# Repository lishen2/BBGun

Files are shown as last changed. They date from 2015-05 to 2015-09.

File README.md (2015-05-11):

BBGun
=============
BBGUN is an infrared shooting system used for entertainment purposes. The project Milestag gave us a lot of inspiration.
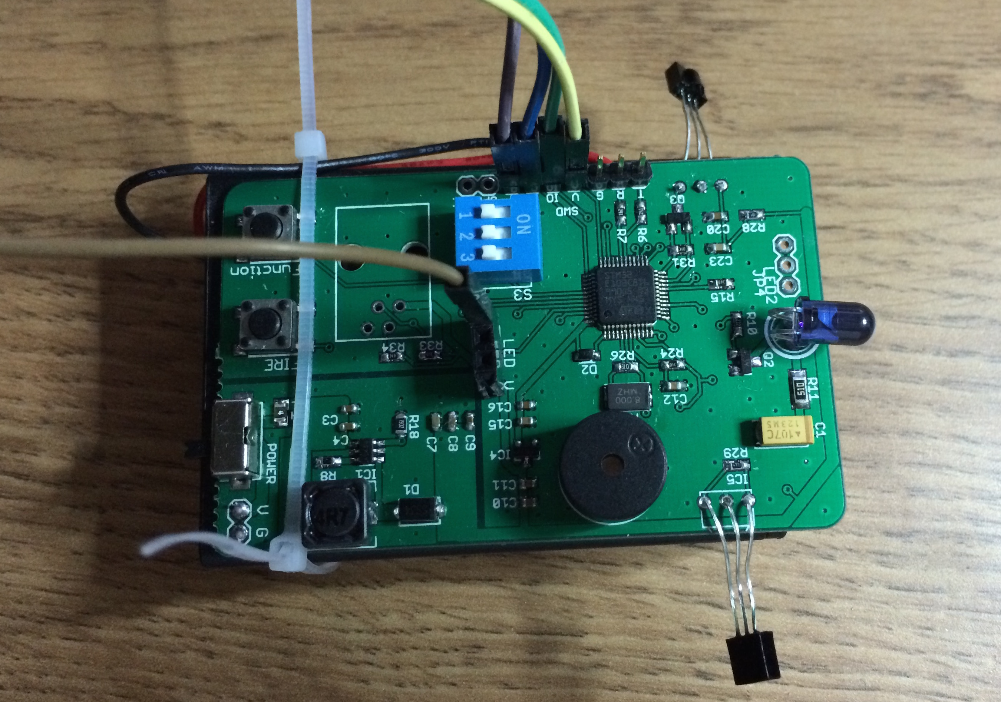
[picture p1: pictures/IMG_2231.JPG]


Hareware resources
-------
* one TSAL6100 IR emitter, two HS0038B IR reciver.
* one RJ9 socket used to connect external reciver(not implemented yet).
* one three key dil switch, used to set group.
* one buzzer controlled by PWM pin.
* two push buttons.

Progress
--------
20150427: First PCB design.     
20150503: Make first test board.  
20150505: LED driver code and buzzer driver code finish.  
20150510: Finish all drivers except IR system.

Developing blog
--------
http://lsgeek.blogspot.com

BBGun
=============
BBGun是一个用于娱乐目的的红外射击系统(真人CS)。Milestag项目给了我们很多启发。

硬件资源
-------
* 一个TSAL6100发射管，两个HS0038B接收管
* 一个RJ9接口用于连接外置接收器（暂未实现）
* 一个三键拨码开关，用于设置分组
* 一个PWM引脚控制的蜂鸣器
* 两个按键

当前进度
--------
20150427: 完成PCB设计   
20150503: 完成第一块PCB的制作   
20150505: 完成LED驱动、蜂鸣器驱动  
20150510: 完成除IR系统外的所有驱动

开发博客
--------
http://blog.sina.com.cn/lgeek

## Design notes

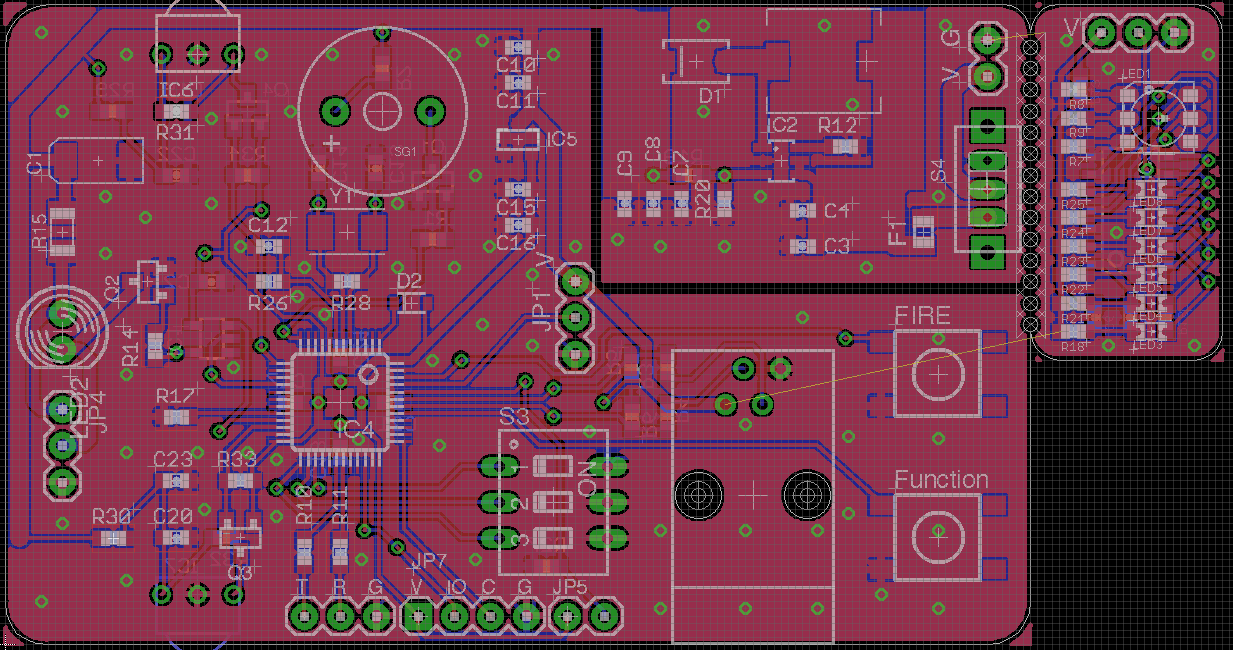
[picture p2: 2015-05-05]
pictures/pcb.png

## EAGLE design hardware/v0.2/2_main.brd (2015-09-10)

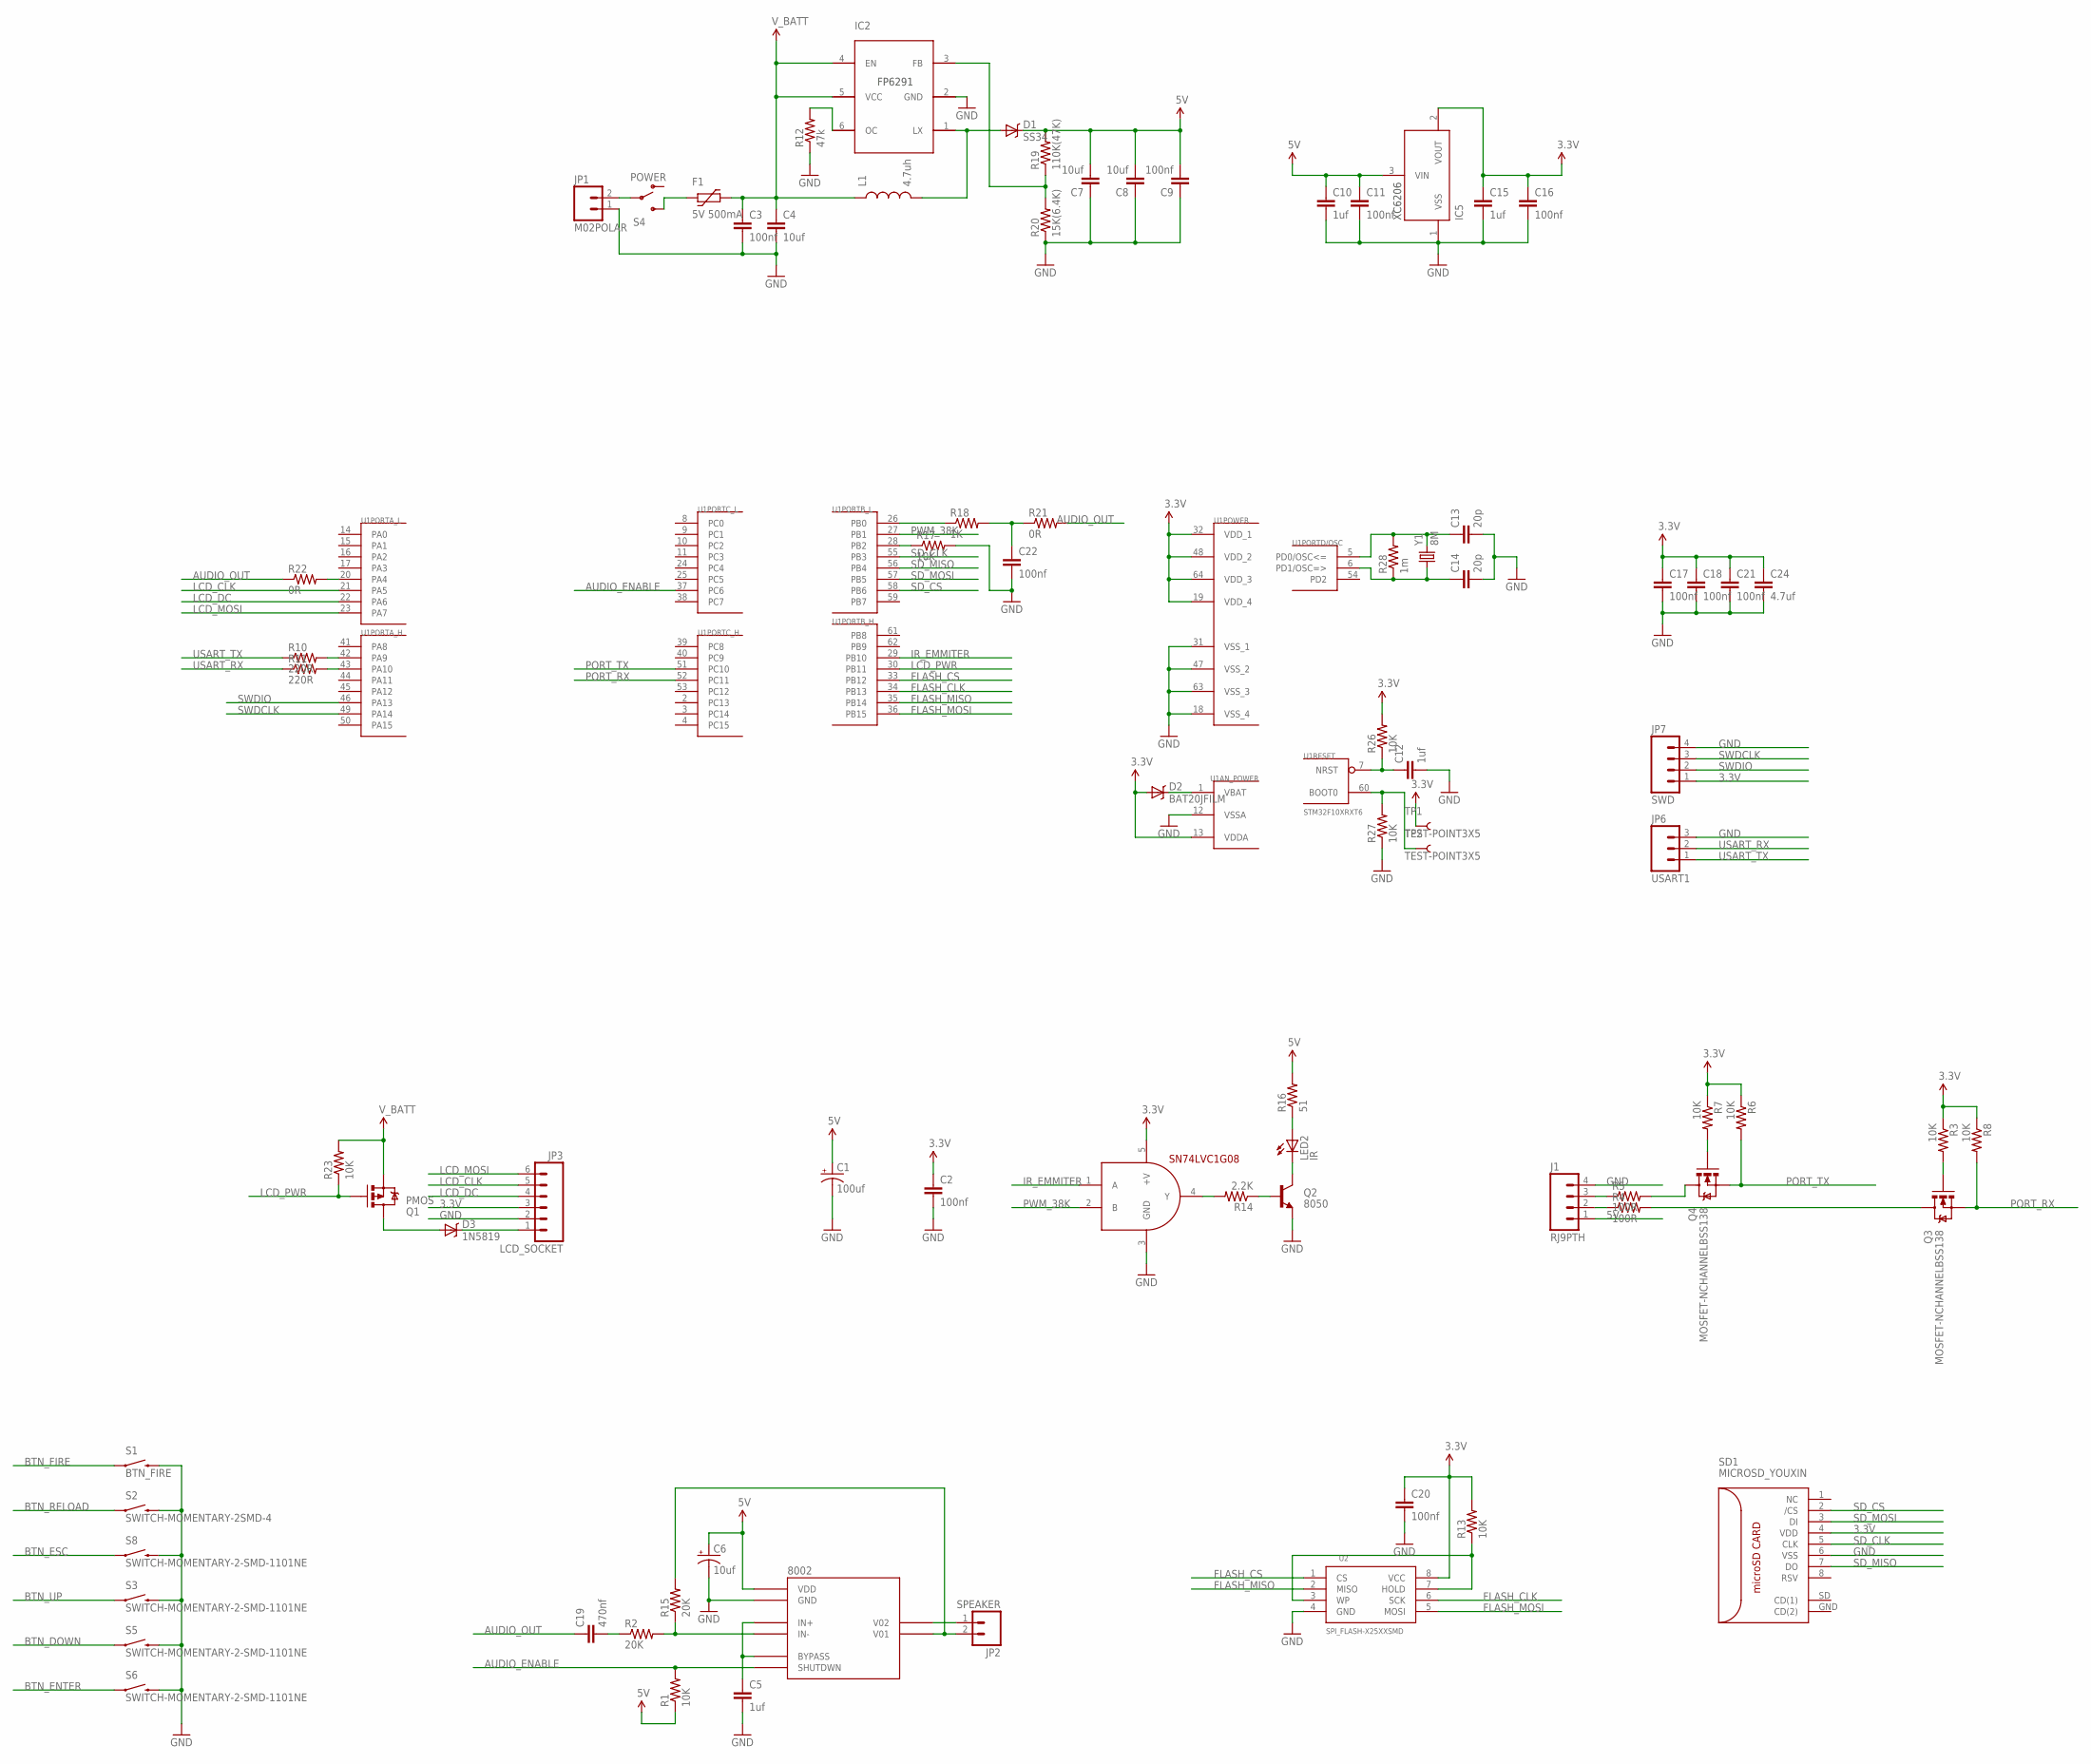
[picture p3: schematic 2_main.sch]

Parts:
8002: LM4871; SO08
C1: 100uf; EIA6032
C2, C3, C9, C11, C16, C17, C18, C20, C21, C22: 100nf; 0603-CAP
C4, C7, C8: 10uf; 0603-CAP
C5, C10, C12, C15: 1uf; 0603-CAP
C6: 10uf; EIA3216-KIT
C13, C14: 20p; 0603-CAP
C19: 470nf; 0603-CAP
C24: 4.7uf; 0603-CAP
D1: SS34; SMA-DIODE
D2: BAT20JFILM; SOD-323
D3: 1N5819; SOD-323
F1: 5V 500mA; R0805
IC1: SN74LVC1G08; SOT23-5
IC2: FP6291; SOT23-6
IC5: XC6206; SOT23-3
J1: RJ9PTH; RJ9
JP1: M02POLAR; MOLEX-1X2
JP2: SPEAKER; MOLEX-1X2
JP3: LCD_SOCKET; MOLEX-1X6
JP6: USART1; 1X03
JP7: SWD; 1X04
L1: 4.7uh; CR75_V2
LED2: IR; LED5MM
Q1: PMOS; SOT23-3
Q2: 8050; SOT23
Q3, Q4: MOSFET-NCHANNELBSS138; SOT23
R1, R3, R6, R7, R8, R13, R17, R23, R26, R27: 10K; 0603-RES
R2, R15: 20K; 0603-RES
R4, R5: 100R; 0603-RES
R10, R11: 220R; 0603-RES
R12: 47k; 0603-RES
R14: 2.2K; 0603-RES
R16: 51; 0603-RES
R18: 1K; 0603-RES
R19: 110K(47K); 0603-RES
R20: 15K(6.4K); 0603-RES
R21, R22: 0R; 0603-RES
R28: 1m; 0603-RES
S1: BTN_FIRE; TACTILE_SWITCH_TALL
S2: SWITCH-MOMENTARY-2SMD-4; TACTILE_SWITCH_TALL
S3, S5, S6, S8: SWITCH-MOMENTARY-2-SMD-1101NE; TACTILE-SWITCH-1101NE
S4: POWER; SWITCH-SPDT-AM#6
SD1: MICROSD_YOUXIN; MICRO_SD_YOUXIN
TP1, TP2: TEST-POINT3X5; PAD.03X.05
U1: STM32F10XRXT6; TQFP64
U2: SPI_FLASH-X25XXSMD; SO08
Y1: 8M; CRYSTAL-TXC-7A

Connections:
3.3V: C2.1, C15.1, C16.1, C17.1, C18.1, C20.1, C21.1, C24.1, D2.2 (A), IC1.5 (+V), IC5.2 (VOUT), JP3.3, JP7.1, R3.1, R6.1, R7.1, R8.1, R13.2, R26.2, SD1.4 (VDD), TP1.P$1, U1.13 (VDDA), U1.19 (VDD_4), U1.32 (VDD_1), U1.48 (VDD_2), U1.64 (VDD_3), U2.8 (VCC)
5V: 8002.6 (VDD), C1.P$1 (+), C6.A (+), C7.2, C8.2, C9.2, C10.1, C11.1, D1.C, IC5.3 (VIN), J1.1, R1.1, R16.2, R19.2
AUDIO_ENABLE: 8002.1 (SHUTDWN), R1.2, U1.37 (PC6)
AUDIO_OUT: C19.1, R21.2, R22.1
BTN_DOWN: S5.P$1 (1)
BTN_ENTER: S6.P$1 (1)
BTN_ESC: S8.P$1 (1)
BTN_FIRE: S1.A2 (1)
BTN_RELOAD: S2.A2 (1)
BTN_UP: S3.P$1 (1)
FLASH_CLK: U1.34 (PB13), U2.6 (SCK)
FLASH_CS: U1.33 (PB12), U2.1 (CS)
FLASH_MISO: U1.35 (PB14), U2.2 (MISO)
FLASH_MOSI: U1.36 (PB15), U2.5 (MOSI)
GND: 8002.7 (GND), C1.P$2 (-), C2.2, C3.2, C4.2, C5.2, C6.C (-), C7.1, C8.1, C9.1, C10.2, C11.2, C12.2, C13.2, C14.2, C15.2, C16.2, C17.2, C18.2, C20.2, C21.2, C22.2, C24.2, IC1.3 (GND), IC2.2 (GND), IC5.1 (VSS), J1.4, JP1.1, JP3.2, JP6.3, JP7.4, Q2.2 (E), R12.1, R17.2, R20.1, R27.1, S1.B2 (2), S2.B2 (2), S3.P$2 (2), S5.P$2 (2), S6.P$2 (2), S8.P$2 (2), SD1.6 (VSS), U1.12 (VSSA), U1.18 (VSS_4), U1.31 (VSS_1), U1.47 (VSS_2), U1.63 (VSS_3), U2.4 (GND)
IR_EMMITER: IC1.1 (A), U1.29 (PB10)
LCD_CLK: JP3.5, U1.21 (PA5)
LCD_DC: JP3.4, U1.22 (PA6)
LCD_MOSI: JP3.6, U1.23 (PA7)
LCD_PWR: Q1.1 (G), R23.1, U1.30 (PB11)
unnamed: R17.1, U1.28 (PB2)
unnamed: R27.2, TP2.P$1, U1.60 (BOOT0)
unnamed: C13.1, R28.2, U1.5 (PD0/OSC<=), Y1.P$2 (2)
unnamed: C14.1, R28.1, U1.6 (PD1/OSC=>), Y1.P$1 (1)
unnamed: D2.1 (C), U1.1 (VBAT)
unnamed: IC1.4 (Y), R14.2
unnamed: JP1.2, S4.2
unnamed: LED2.K (C), Q2.3 (C)
unnamed: Q2.1 (B), R14.1
unnamed: F1.1, S4.3 (S)
unnamed: Q3.3 (D), R4.2
unnamed: J1.3, R5.1
unnamed: Q4.3 (D), R5.2
unnamed: R18.1, U1.26 (PB0)
unnamed: 8002.8 (V02), JP2.1
unnamed: Q4.1 (G), R7.2
unnamed: Q3.1 (G), R3.2
unnamed: 8002.5 (V01), JP2.2, R15.2
unnamed: C19.2, R2.1
unnamed: LED2.A, R16.1
unnamed: 8002.4 (IN-), R2.2, R15.1
unnamed: D1.A, IC2.1 (LX), L1.P$2 (2)
unnamed: IC2.6 (OC), R12.2
unnamed: 8002.2 (BYPASS), 8002.3 (IN+), C5.1
unnamed: IC2.3 (FB), R19.1, R20.2
unnamed: R13.1, U2.3 (WP), U2.7 (HOLD)
unnamed: R10.2, U1.42 (PA9)
unnamed: R11.2, U1.43 (PA10)
unnamed: D3.1 (C), JP3.1
unnamed: C22.1, R18.2, R21.1
unnamed: R22.2, U1.20 (PA4)
unnamed: D3.2 (A), Q1.3 (D)
unnamed: J1.2, R4.1
unnamed: C12.1, R26.1, U1.7 (NRST)
PORT_RX: Q3.2 (S), R8.2, U1.52 (PC11)
PORT_TX: Q4.2 (S), R6.2, U1.51 (PC10)
PWM_38K: IC1.2 (B), U1.27 (PB1)
SD_CLK: SD1.5 (CLK), U1.55 (PB3)
SD_CS: SD1.2 (/CS), U1.58 (PB6)
SD_MISO: SD1.7 (DO), U1.56 (PB4)
SD_MOSI: SD1.3 (DI), U1.57 (PB5)
SWDCLK: JP7.3, U1.49 (PA14)
SWDIO: JP7.2, U1.46 (PA13)
USART_RX: JP6.2, R11.1
USART_TX: JP6.1, R10.1
V_BATT: C3.1, C4.1, F1.2, IC2.4 (EN), IC2.5 (VCC), L1.P$1 (1), Q1.2 (S), R23.2

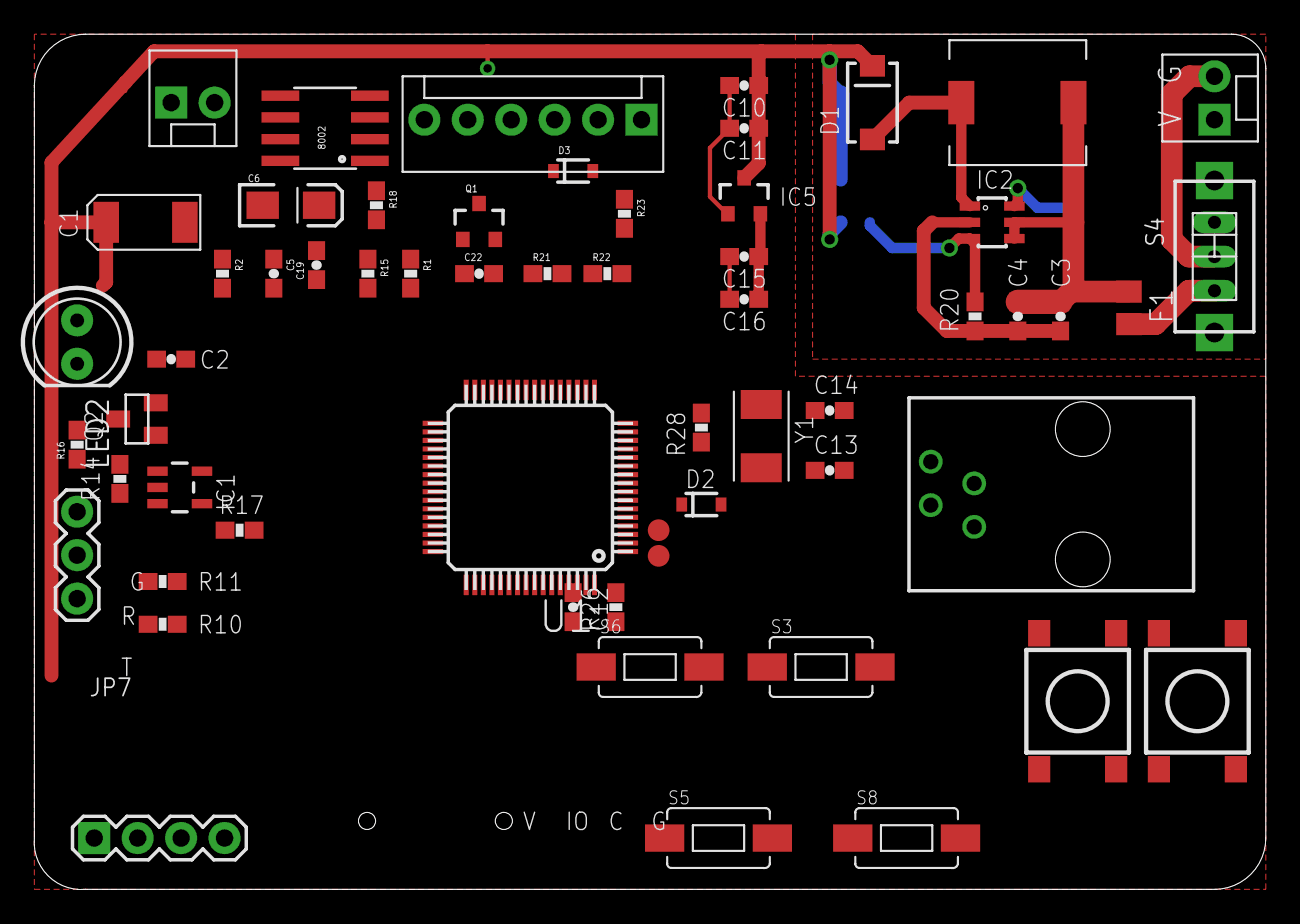
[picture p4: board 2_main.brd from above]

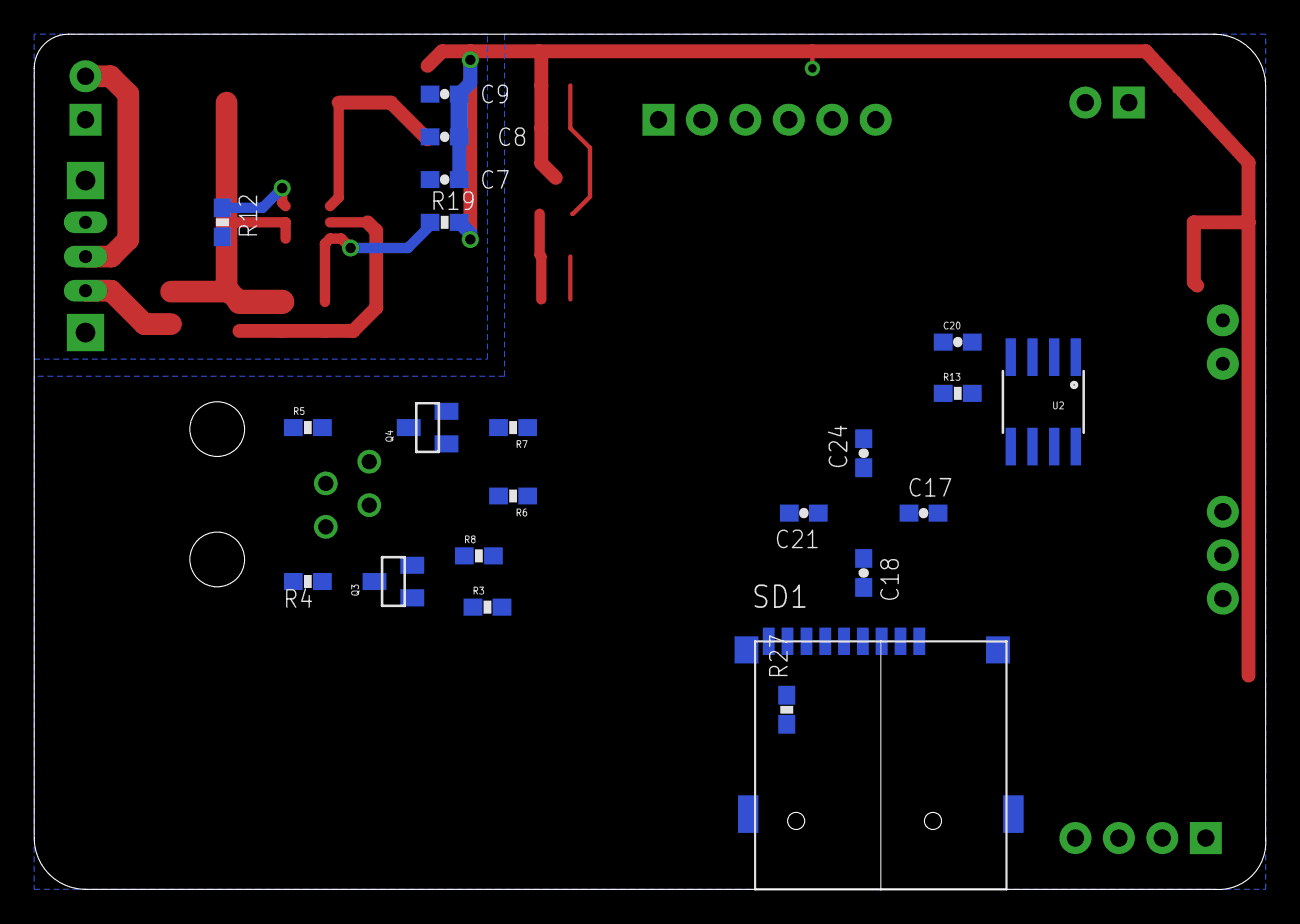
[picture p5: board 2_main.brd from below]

Board: 2 copper layers, 72.0 x 50.0 mm, 81 parts (22 on the bottom side), 60 nets.

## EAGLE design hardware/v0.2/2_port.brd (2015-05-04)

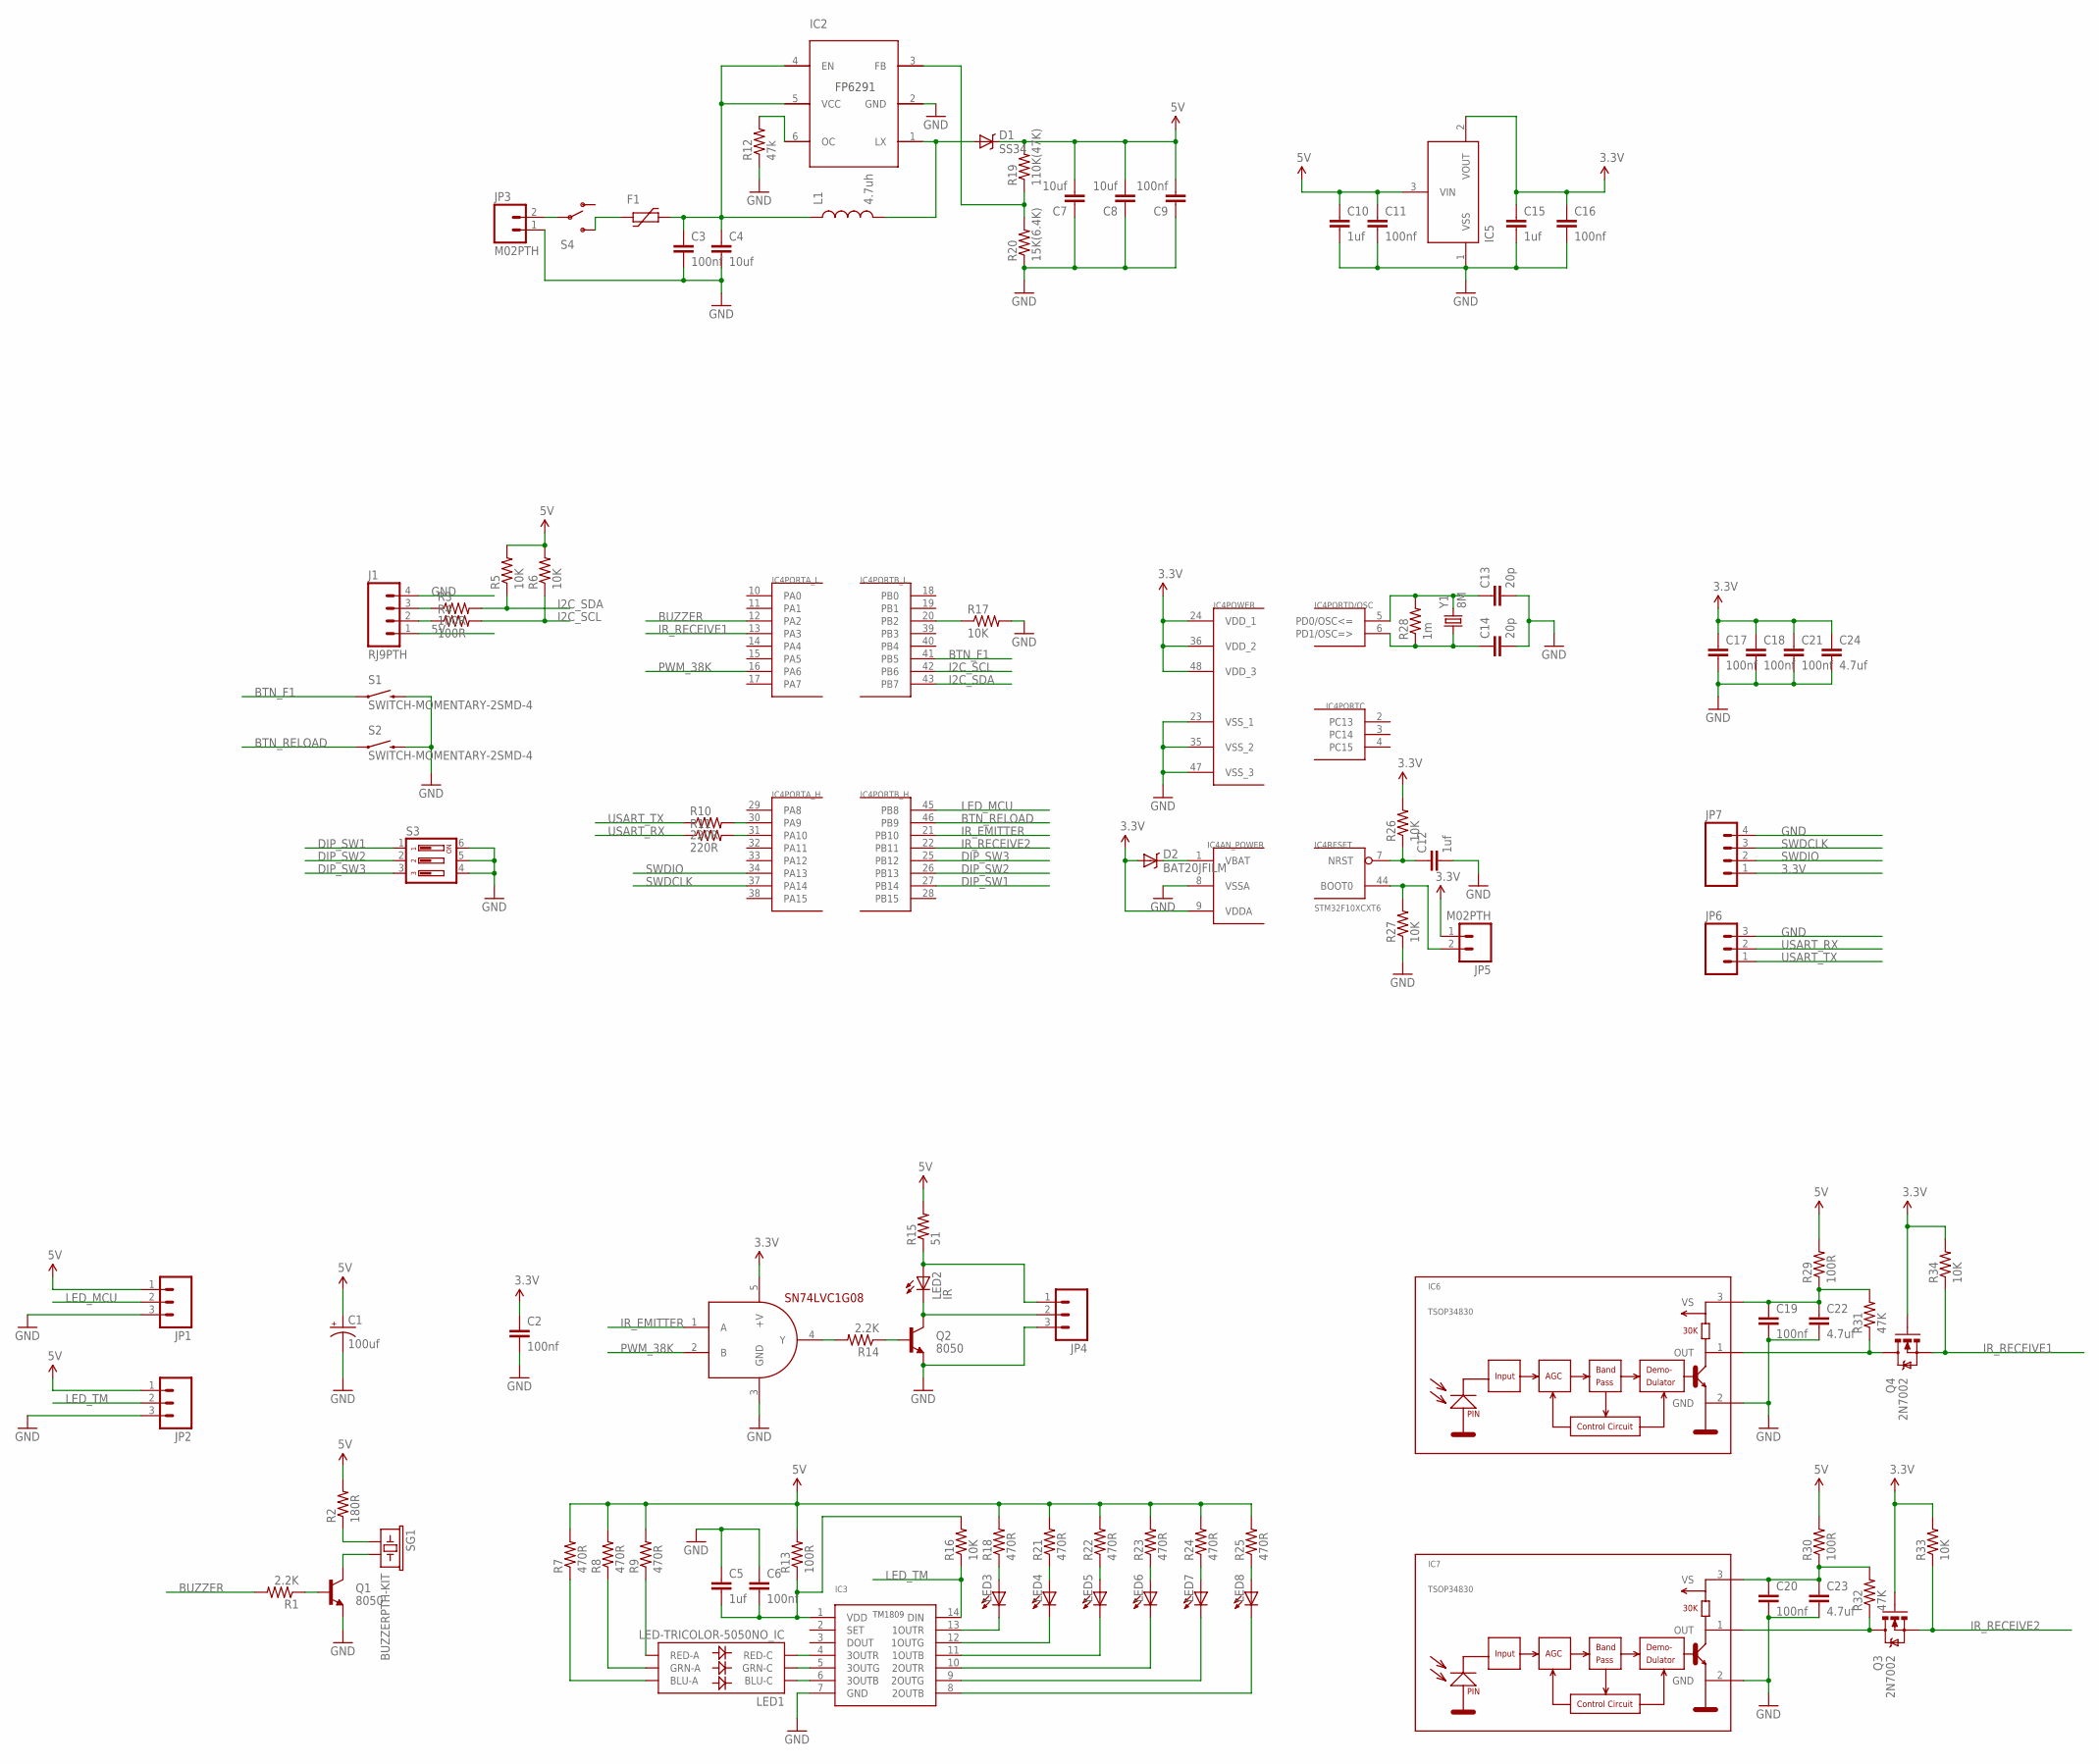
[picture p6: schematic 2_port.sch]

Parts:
C1: 100uf; EIA6032
C2, C3, C6, C9, C11, C16, C17, C18, C19, C20, C21: 100nf; 0603-CAP
C4, C7, C8: 10uf; 0603-CAP
C5, C10, C12, C15: 1uf; 0603-CAP
C13, C14: 20p; 0603-CAP
C22, C23, C24: 4.7uf; 0603-CAP
D1: SS34; SMA-DIODE
D2: BAT20JFILM; SOD-323
F1: PTC-FUSE; R0805
IC1: SN74LVC1G08; SOT23-5
IC2: FP6291; SOT23-6
IC3: TM1809; SOP-14
IC4: STM32F10XCXT6; TQFP48
IC5: XC6206; SOT23-3
IC6, IC7: TSOP34830; TSOP348
J1: RJ9PTH; RJ9
JP1, JP2, JP4, JP6: M03PTH; 1X03
JP3, JP5: M02PTH; 1X02
JP7: M04PTH; 1X04
L1: 4.7uh; CR75_V2
LED1: LED-TRICOLOR-5050NO_IC; LED-TRICOLOR-5050
LED2: IR; LED5MM
LED3, LED4, LED5, LED6, LED7, LED8: LED0805; CHIPLED_0805
Q1, Q2: 8050; SOT23
Q3, Q4: 2N7002; SOT23
R1, R14: 2.2K; 0603-RES
R2: 180R; 0603-RES
R3, R4, R13, R29, R30: 100R; 0603-RES
R5, R6, R16, R17, R26, R27, R33, R34: 10K; 0603-RES
R7, R8, R9, R18, R21, R22, R23, R24, R25: 470R; 0603-RES
R10, R11: 220R; 0603-RES
R12: 47k; 0603-RES
R15: 51; 1206
R19: 110K(47K); 0603-RES
R20: 15K(6.4K); 0603-RES
R28: 1m; 0603-RES
R31, R32: 47K; 0603-RES
S1, S2: SWITCH-MOMENTARY-2SMD-4; TACTILE_SWITCH_TALL
S3: DIP03YL
S4: SWITCH-SPST3AM6; SWITCH-SPDT-AM#6
SG1: BUZZERPTH-KIT; BUZZER-12MM-KIT
Y1: 8M; CRYSTAL-TXC-7A

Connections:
3.3V: C2.1, C15.1, C16.1, C17.1, C18.1, C21.1, C24.1, D2.2 (A), IC1.5 (+V), IC4.9 (VDDA), IC4.24 (VDD_1), IC4.36 (VDD_2), IC4.48 (VDD_3), IC5.2 (VOUT), JP5.1, JP7.1, Q3.1 (G), Q4.1 (G), R26.2, R33.2, R34.2
5V: C1.P$1 (+), C7.2, C8.2, C9.2, C10.1, C11.1, D1.C, IC5.3 (VIN), J1.1, JP1.1, JP2.1, R2.2, R5.2, R6.2, R7.2, R8.2, R9.2, R13.2, R15.2, R18.2, R19.2, R21.2, R22.2, R23.2, R24.2, R25.2, R29.2, R30.2
BTN_F1: IC4.41 (PB5), S1.A2 (1)
BTN_RELOAD: IC4.46 (PB9), S2.A2 (1)
BUZZER: IC4.12 (PA2), R1.2
DIP_SW1: IC4.27 (PB14), S3.1
DIP_SW2: IC4.26 (PB13), S3.2
DIP_SW3: IC4.25 (PB12), S3.3
GND: C1.P$2 (-), C2.2, C3.2, C4.2, C5.1, C6.1, C7.1, C8.1, C9.1, C10.2, C11.2, C12.2, C13.2, C14.2, C15.2, C16.2, C17.2, C18.2, C19.2, C20.2, C21.2, C22.2, C23.2, C24.2, IC1.3 (GND), IC2.2 (GND), IC3.7 (GND), IC4.8 (VSSA), IC4.23 (VSS_1), IC4.35 (VSS_2), IC4.47 (VSS_3), IC5.1 (VSS), IC6.2 (GND), IC7.2 (GND), J1.4, JP1.3, JP2.3, JP3.1, JP4.3, JP6.3, JP7.4, Q1.2 (E), Q2.2 (E), R12.1, R17.2, R20.1, R27.1, S1.B2 (2), S2.B2 (2), S3.4, S3.5, S3.6
I2C_SCL: IC4.42 (PB6), R4.2, R6.1
I2C_SDA: IC4.43 (PB7), R3.2, R5.1
IR_EMITTER: IC1.1 (A), IC4.21 (PB10)
IR_RECEIVE1: IC4.13 (PA3), Q4.2 (S), R34.1
IR_RECEIVE2: IC4.22 (PB11), Q3.2 (S), R33.1
LED_MCU: IC4.45 (PB8), JP1.2
LED_TM: IC3.14 (DIN), JP2.2, R16.1
unnamed: IC4.20 (PB2), R17.1
unnamed: IC4.44 (BOOT0), JP5.2, R27.2
unnamed: C13.1, IC4.5 (PD0/OSC<=), R28.2, Y1.P$2 (2)
unnamed: C14.1, IC4.6 (PD1/OSC=>), R28.1, Y1.P$1 (1)
unnamed: D2.1 (C), IC4.1 (VBAT)
unnamed: IC1.4 (Y), R14.2
unnamed: JP3.2, S4.2
unnamed: JP4.2, LED2.K (C), Q2.3 (C)
unnamed: Q2.1 (B), R14.1
unnamed: F1.1, S4.3 (S)
unnamed: C19.1, C22.1, IC6.3 (VS), R29.1, R31.2
unnamed: C20.1, C23.1, IC7.3 (VS), R30.1, R32.2
unnamed: IC3.4 (3OUTR), LED1.5 (RED-C)
unnamed: JP4.1, LED2.A, R15.1
unnamed: IC3.5 (3OUTG), LED1.6 (GRN-C)
unnamed: IC3.6 (3OUTB), LED1.4 (BLU-C)
unnamed: LED1.2 (RED-A), R9.1
unnamed: LED1.1 (GRN-A), R8.1
unnamed: LED1.3 (BLU-A), R7.1
unnamed: C3.1, C4.1, F1.2, IC2.4 (EN), IC2.5 (VCC), L1.P$1 (1)
unnamed: IC3.13 (1OUTR), LED3.C
unnamed: D1.A, IC2.1 (LX), L1.P$2 (2)
unnamed: IC2.6 (OC), R12.2
unnamed: LED3.A, R18.1
unnamed: IC2.3 (FB), R19.1, R20.2
unnamed: LED4.A, R21.1
unnamed: IC3.12 (1OUTG), LED4.C
unnamed: IC3.11 (1OUTB), LED5.C
unnamed: IC3.10 (2OUTR), LED6.C
unnamed: IC3.9 (2OUTG), LED7.C
unnamed: IC3.8 (2OUTB), LED8.C
unnamed: LED5.A, R22.1
unnamed: LED6.A, R23.1
unnamed: LED7.A, R24.1
unnamed: LED8.A, R25.1
unnamed: C5.2, C6.2, IC3.1 (VDD), R13.1, R16.2
unnamed: IC4.30 (PA9), R10.2
unnamed: IC4.31 (PA10), R11.2
unnamed: J1.3, R3.1
unnamed: J1.2, R4.1
unnamed: R2.1, SG1.+ (1)
unnamed: Q1.3 (C), SG1.- (2)
unnamed: Q1.1 (B), R1.1
unnamed: C12.1, IC4.7 (NRST), R26.1
unnamed: IC6.1 (OUT), Q4.3 (D), R31.1
unnamed: IC7.1 (OUT), Q3.3 (D), R32.1
PWM_38K: IC1.2 (B), IC4.16 (PA6)
SWDCLK: IC4.37 (PA14), JP7.3
SWDIO: IC4.34 (PA13), JP7.2
USART_RX: JP6.2, R11.1
USART_TX: JP6.1, R10.1

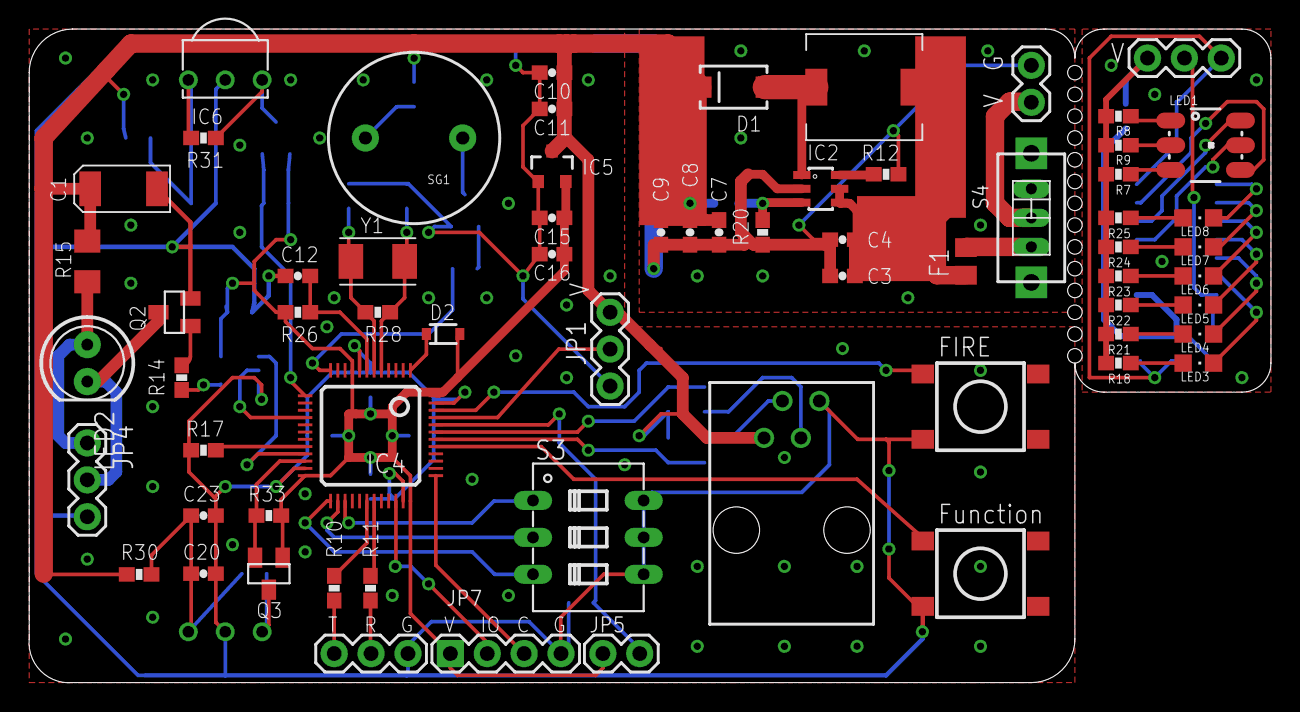
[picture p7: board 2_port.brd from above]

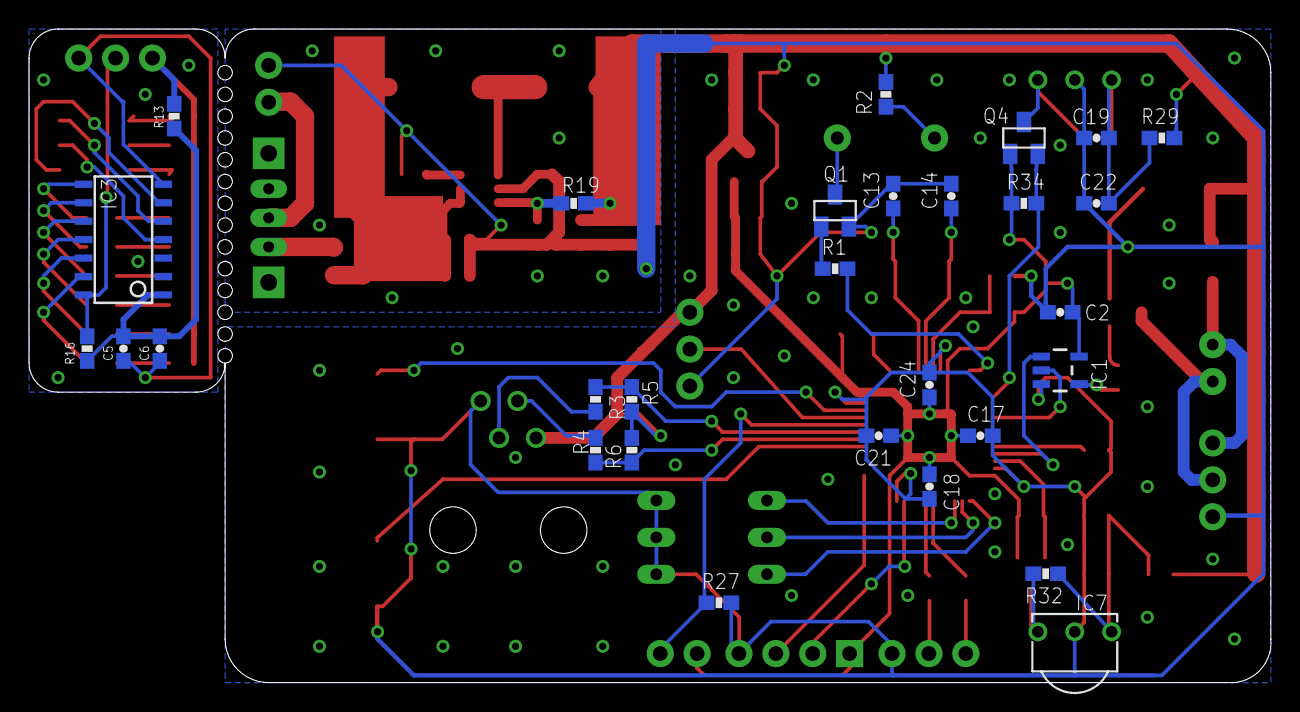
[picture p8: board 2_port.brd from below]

Board: 2 copper layers, 85.5 x 45.0 mm, 95 parts (29 on the bottom side), 67 nets.

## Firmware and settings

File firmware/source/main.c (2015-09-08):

#include <stdio.h>
#include "stm32f10x.h"
#include "public.h"
#include "led.h"
#include "ir.h"
#include "menu.h"
#include "ringbuf.h"
#include "usart_io.h"
#include "button.h"

int main()
{
	system_init();
	usartio_init_usart1(); 
	usartio_init_usart2();
	usartio_init_usart3();
	button_init();
	ir_init();
    
	printf("started\n");

	//ir_send_shot(0x01, 0x02, 0x03);
	while(1){
		
        ir_handle_msg();
        logic_handle_key();

		delay_ms(20);
	}

	return 0;
}

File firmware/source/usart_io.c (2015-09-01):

#include <stdio.h>
#include <string.h>
#include "stm32f10x.h"
#include "ringbuf.h"
#include "usart_io.h"
#include "public.h"

#define USARTIO_FLAG_RXNE  0x20
#define USARTIO_FLAG_TXE   0x80

#define USARTIO_IsFlagSet(USART_ADDR, FLAG) (0 != (USART_ADDR->SR & FLAG))

//USART1 used to print debug information and firmware upgrade
#define USARTIO_USART1_GPIO       GPIOA
#define USARTIO_USART1_GPIO_CLK   RCC_APB2Periph_GPIOA
#define USARTIO_USART1_RxPin      GPIO_Pin_10
#define USARTIO_USART1_TxPin      GPIO_Pin_9
#define USARTIO_USART1_CLK        RCC_APB2Periph_USART1
#define USARTIO_USART1_IRQ        USART1_IRQn

//USART2 and USART3 RX pin connect to two IR receive ICs,
//USART3 TX pin connect IR emitter diode
#define USARTIO_USART2_GPIO      GPIOA
#define USARTIO_USART2_GPIO_CLK  RCC_APB2Periph_GPIOA
#define USARTIO_USART2_RxPin     GPIO_Pin_3
#define USARTIO_USART2_CLK       RCC_APB1Periph_USART2
#define USARTIO_USART2_IRQ       USART2_IRQn

#define USARTIO_USART3_GPIO      GPIOB
#define USARTIO_USART3_GPIO_CLK  RCC_APB2Periph_GPIOB
#define USARTIO_USART3_RxPin     GPIO_Pin_11
#define USARTIO_USART3_TxPin     GPIO_Pin_10
#define USARTIO_USART3_CLK       RCC_APB1Periph_USART3
#define USARTIO_USART3_IRQ       USART3_IRQn

/* USART1 send and receive buffer size */
#define USARTIO_U1_READBUF_SIZE  64 
#define USARTIO_U1_WRITEBUF_SIZE 1024

/* USART2 is receive only, USART3 use polling mode to send, so they both not use send buffer */
#define USARTIO_U2_READBUF_SIZE  256 
#define USARTIO_U3_READBUF_SIZE  256 

static unsigned char g_usart1_readbuf[USARTIO_U1_READBUF_SIZE]; 
static unsigned char g_usart1_writebuf[USARTIO_U1_WRITEBUF_SIZE]; 
struct ringbuf_struct g_Usart1ReadBufHead = {
    0,
    0,
    sizeof(g_usart1_readbuf),
    g_usart1_readbuf,
};
struct ringbuf_struct g_Usart1WriteBufHead = {
    0,
    0,
    sizeof(g_usart1_writebuf),
    g_usart1_writebuf,
};

static unsigned char g_usart2_readbuf[USARTIO_U2_READBUF_SIZE]; 
struct ringbuf_struct g_Usart2ReadBufHead = {
    0,
    0,
    sizeof(g_usart2_readbuf),
    g_usart2_readbuf,
};

static unsigned char g_usart3_readbuf[USARTIO_U3_READBUF_SIZE];  
struct ringbuf_struct g_Usart3ReadBufHead = {
    0,
    0,
    sizeof(g_usart3_readbuf),
    g_usart3_readbuf,
};

static USART_InitTypeDef USART_InitStructure;

int usartio_sendchar(void* port, unsigned char ch)
{  
    int ret;

	//usart1 use interrupt mode
    if (USART1 == port){
	    ret = ringbuf_putchar(&g_Usart1WriteBufHead, ch);
	    USART_ITConfig(port, USART_IT_TXE, ENABLE);
    } 
	else {
        return ERR_FAILED;
    }

    return ret;
}

int usartio_sendchar_polling(void* port, unsigned char ch)
{  
	//usart3 use polling mode
	if (USART3 == port){
	    USART_SendData(port, ch);
	    while(USART_GetFlagStatus(port, USART_FLAG_TXE) == RESET);
    } else {
        return ERR_FAILED;
    }

    return ERR_OK;
}

int usartio_recvchar(void *port, unsigned char *ch, int timeout)
{
    int ret;
    struct ringbuf_struct *readBuf;

    if (USART1 == port){
        readBuf = &g_Usart1ReadBufHead;
    } else if (USART2 == port){
        readBuf = &g_Usart2ReadBufHead;
    } else if (USART3 == port){
        readBuf = &g_Usart3ReadBufHead;
    } else {
        return ERR_FAILED;
    }

    timeout += g_jiffies;
    while (1){
        ret = ringbuf_getchar(readBuf, ch);
        if (ERR_OK == ret || time_after(g_jiffies, timeout)){
            break;
        }
    }

    return ret;
}

int usartio_receive_count(void *port)
{
	struct ringbuf_struct *readBuf;

    if (USART1 == port){
        readBuf = &g_Usart1ReadBufHead;
    } else if (USART2 == port){
        readBuf = &g_Usart2ReadBufHead;
    } else if (USART3 == port){
        readBuf = &g_Usart3ReadBufHead;
    } else {
        return 0;
    }

	return ringbuf_getcount(readBuf);
}

void usartio_init_usart1(void)
{
    NVIC_InitTypeDef NVIC_InitStructure;
    GPIO_InitTypeDef GPIO_InitStructure;    

    RCC_APB2PeriphClockCmd(USARTIO_USART1_GPIO_CLK, ENABLE);
    RCC_APB2PeriphClockCmd(USARTIO_USART1_CLK, ENABLE);

    /* Enable the USART Interrupt */
    NVIC_InitStructure.NVIC_IRQChannel = USARTIO_USART1_IRQ;
	NVIC_InitStructure.NVIC_IRQChannelPreemptionPriority = 0;
    NVIC_InitStructure.NVIC_IRQChannelSubPriority = 0;
    NVIC_InitStructure.NVIC_IRQChannelCmd = ENABLE;
    NVIC_Init(&NVIC_InitStructure);

    /* GPIO */
    /* Configure Rx as input floating */
    GPIO_InitStructure.GPIO_Pin = USARTIO_USART1_RxPin;
    GPIO_InitStructure.GPIO_Speed = GPIO_Speed_50MHz;
    GPIO_InitStructure.GPIO_Mode = GPIO_Mode_IN_FLOATING;
    GPIO_Init(USARTIO_USART1_GPIO, &GPIO_InitStructure);

    /* Configure Tx as alternate function push-pull */
    GPIO_InitStructure.GPIO_Pin = USARTIO_USART1_TxPin;
    GPIO_InitStructure.GPIO_Mode = GPIO_Mode_AF_PP;
    GPIO_Init(USARTIO_USART1_GPIO, &GPIO_InitStructure);

    USART_InitStructure.USART_BaudRate = 115200;
    USART_InitStructure.USART_WordLength = USART_WordLength_8b;
    USART_InitStructure.USART_StopBits = USART_StopBits_1;
    USART_InitStructure.USART_Parity = USART_Parity_No;
    USART_InitStructure.USART_HardwareFlowControl = USART_HardwareFlowControl_None;
    USART_InitStructure.USART_Mode = USART_Mode_Rx | USART_Mode_Tx;
    USART_Init(USART1, &USART_InitStructure);

    /* enable interrupt */
    USART_ITConfig(USART1, USART_IT_RXNE, ENABLE);
    USART_ITConfig(USART1, USART_IT_TXE, ENABLE);

    USART_Cmd(USART1, ENABLE);

    return;
}
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

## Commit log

2015-04-19 add schematic
    [1.brd, 1.sch]
2015-04-19 start wiring
    [1.brd, 1.sch]
2015-04-23 nearly finish
    [1.brd, 1.sch]
2015-04-24 finish wire
    [1.brd, 1.sch]
2015-04-26 found some mistake, wait fixup
    [1.brd, 1.sch]
2015-04-27 modify some packages
    [1.brd, 1.sch]
2015-05-04 update silkscreen
    [1.brd, 1.sch]
2015-05-18 fix switch issue
2015-09-05 drawing v0.2 pcb
    [2_main.brd, 2_main.sch, 2_port.brd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]
2015-09-06 update sch
    [2_main.brd, 2_main.sch]
2015-09-09 add mirco sd socket
    [2_main.brd, 2_main.sch]
2015-09-10 update pcb
    [2_main.brd, 2_main.sch]

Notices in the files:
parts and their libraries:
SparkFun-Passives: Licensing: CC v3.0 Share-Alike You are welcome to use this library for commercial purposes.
